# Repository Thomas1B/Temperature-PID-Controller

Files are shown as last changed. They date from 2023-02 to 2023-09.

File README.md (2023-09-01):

# Temperature PID Controller using an Arduino

This project uses a PID controller algorithm to heat up a heating cartridge and maintain an accurate temperature using an Arduino nano.
<br><br>

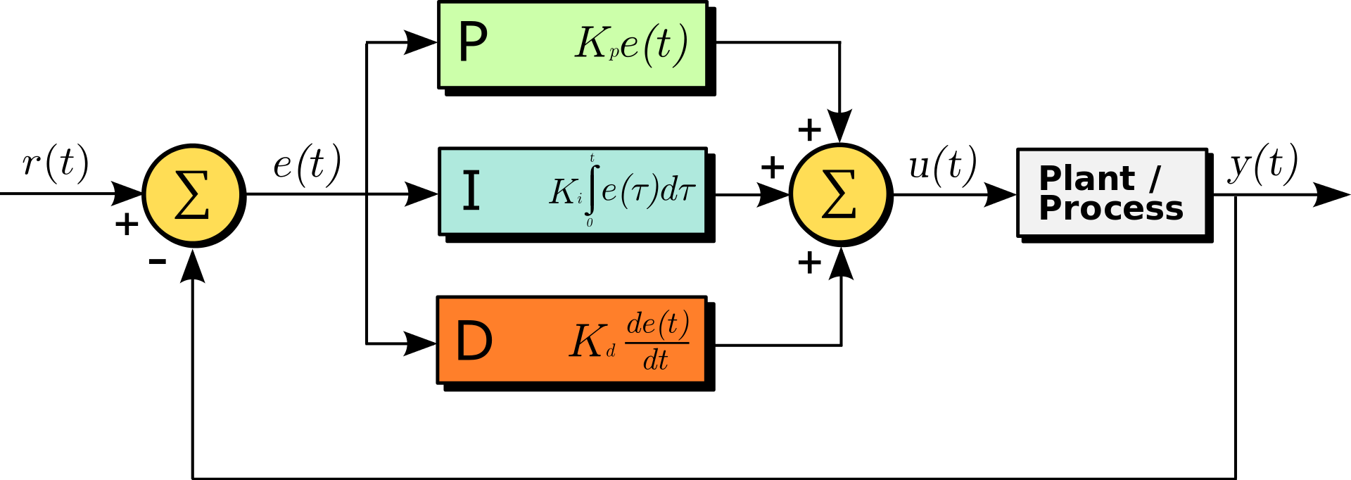
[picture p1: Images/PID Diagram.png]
PID Diagram
<br>

## Schematic

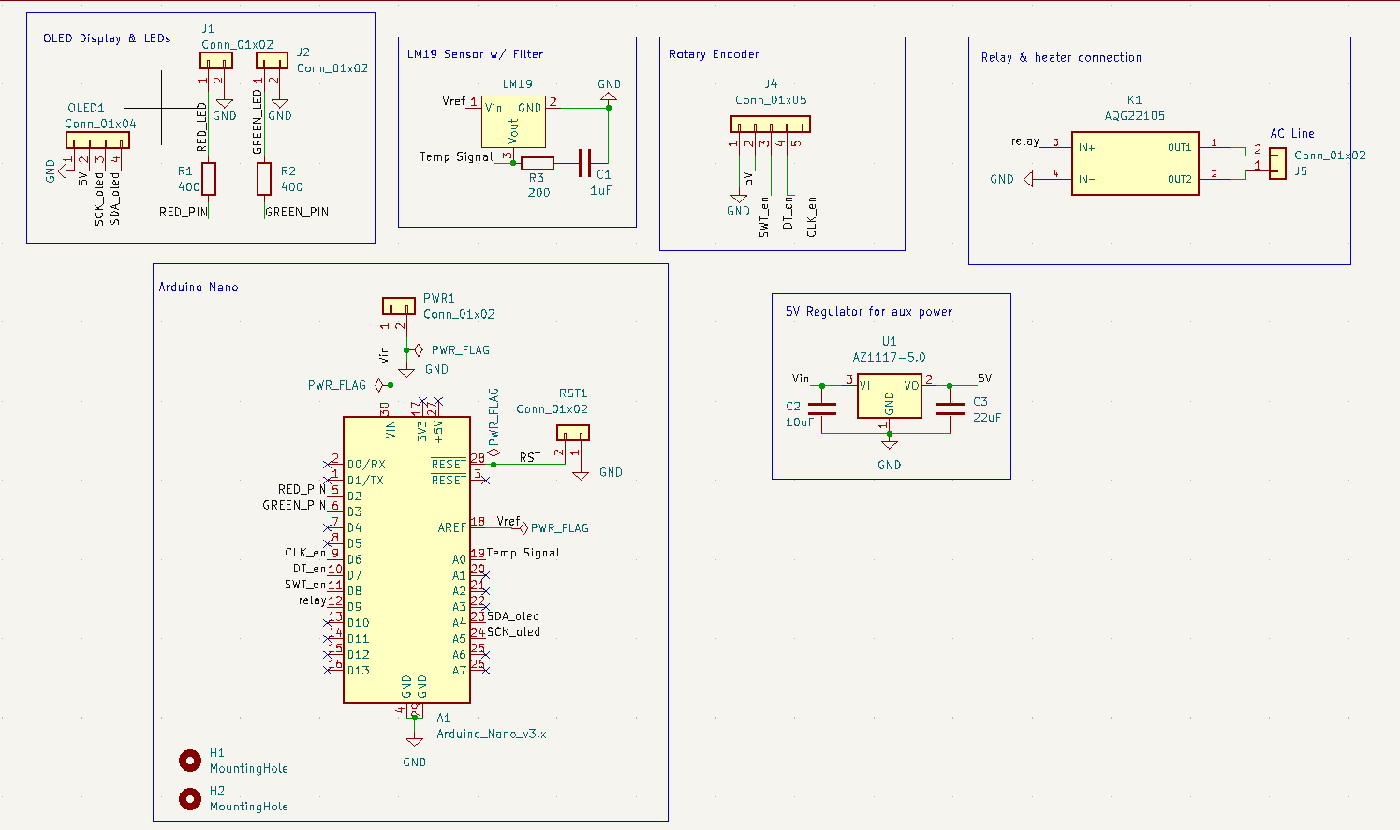
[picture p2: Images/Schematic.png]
Schematic
<br>

## Parts List

See `Parts_list.csv`

## Controls

1. Single-press to reset set temperature.
2. Double-press increase increment step for changing set temperature.
3. Press & hold to start up heating process.

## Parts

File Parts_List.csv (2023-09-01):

Index | Requested Quantity 1 | Pack Quantity 1 | Pack Type 1 | Digi-Key Part Number 1 | Unit Price 1 | Extended Price 1 | Minimum Order Quantity 1
1 | 1 | 1 | Bulk | 1050-ABX00028-ND | 19.71000 | $19.71 | 1
2 | 1 | 1 | Cut Tape (CT) | 296-48469-1-ND | 1.75000 | $1.75 | 1
3 | 1 | 1 | Tube | 255-2102-5-ND | 7.88000 | $7.88 | 1
4 | 4 | 4 | Bulk | 455-B2B-XH-A-ND | 0.22000 | $0.88 | 1
5 | 1 | 1 | Box | 455-B5B-XH-A-ND | 0.39000 | $0.39 | 1
6 | 1 | 1 | Bulk | 455-B4B-XH-A-ND | 0.32000 | $0.32 | 1
7 | 1 | 1 | Cut Tape (CT) | 1276-1066-1-ND | 0.14000 | $0.14 | 1
8 | 1 | 1 | Cut Tape (CT) | 1276-2891-1-ND | 0.26000 | $0.26 | 1
9 | 1 | 1 | Cut Tape (CT) | 1276-CL21A226MAYNNNECT-ND | 0.36000 | $0.36 | 1
10 | 1 | 1 | Cut Tape (CT) | AZ1117IH-5.0TRG1DICT-ND | 0.58000 | $0.58 | 1
11 | 1 | 1 | Bulk | 277-12547-ND | 0.73000 | $0.73 | 1
12 | 2 | 2 | Tray | S7013-ND | 1.42000 | $2.84 | 1
13 | 1 | 1 | Bulk | 754-1263-ND | 0.15000 | $0.15 | 1
14 | 1 | 1 | Bulk | 754-1264-ND | 0.15000 | $0.15 | 1
15 | 2 | 2 | Cut Tape (CT) | 311-392CRCT-ND | 0.15000 | $0.30 | 1
16 | 1 | 1 | Cut Tape (CT) | 13-RC0805FR-10200RLCT-ND | 0.15000 | $0.15 | 1
17 | 1 | 1 | Bulk | EG2025-ND | 2.36000 | $2.36 | 1
18 | 1 | 1 | Bulk | 455-2219-ND | 0.17000 | $0.17 | 1
19 | 1 | 1 | Bag | 455-2267-ND | 0.17000 | $0.17 | 1
20 | 1 | 1 | Bag | 455-2268-ND | 0.20000 | $0.20 | 1
21 | 4 | 4 | Bulk | 455-2266-ND | 0.15000 | $0.60 | 1
22 | 50 | 50 | Cut Tape (CT) | 455-4220-1-ND | 0.06680 | $3.34 | 1
23 | 1 | 1 | Bulk | 455-2248-ND | 0.30000 | $0.30 | 1

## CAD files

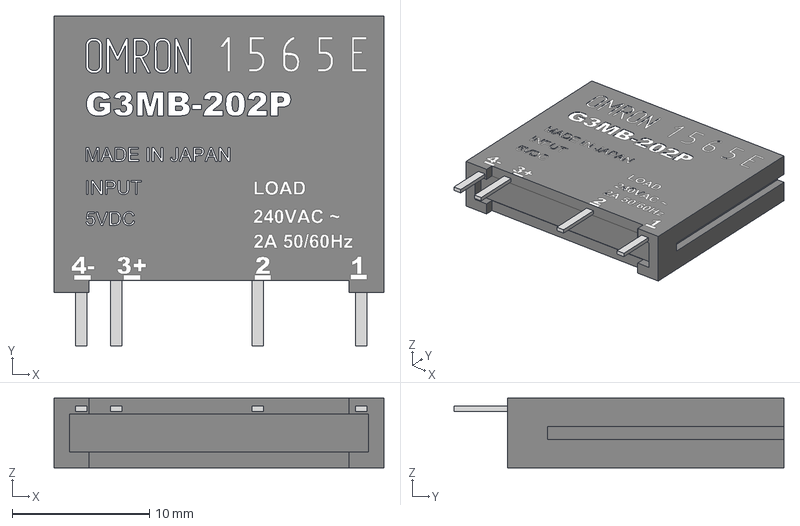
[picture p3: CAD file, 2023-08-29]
3D Models/G3MB-202P DC5 Relay.step
24.1 x 24.1 x 5.08 mm

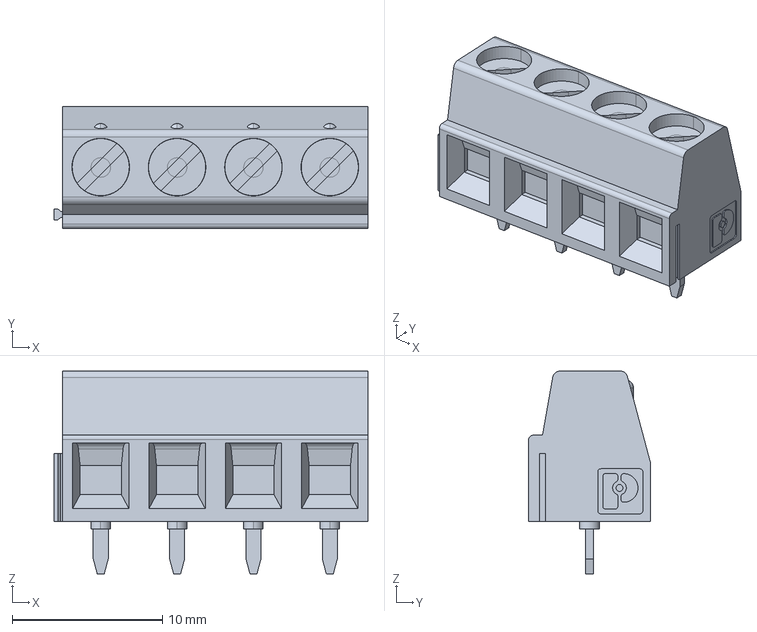
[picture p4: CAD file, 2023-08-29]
3D Models/terminal block - 4.stp
20.9 x 8.10 x 13.5 mm

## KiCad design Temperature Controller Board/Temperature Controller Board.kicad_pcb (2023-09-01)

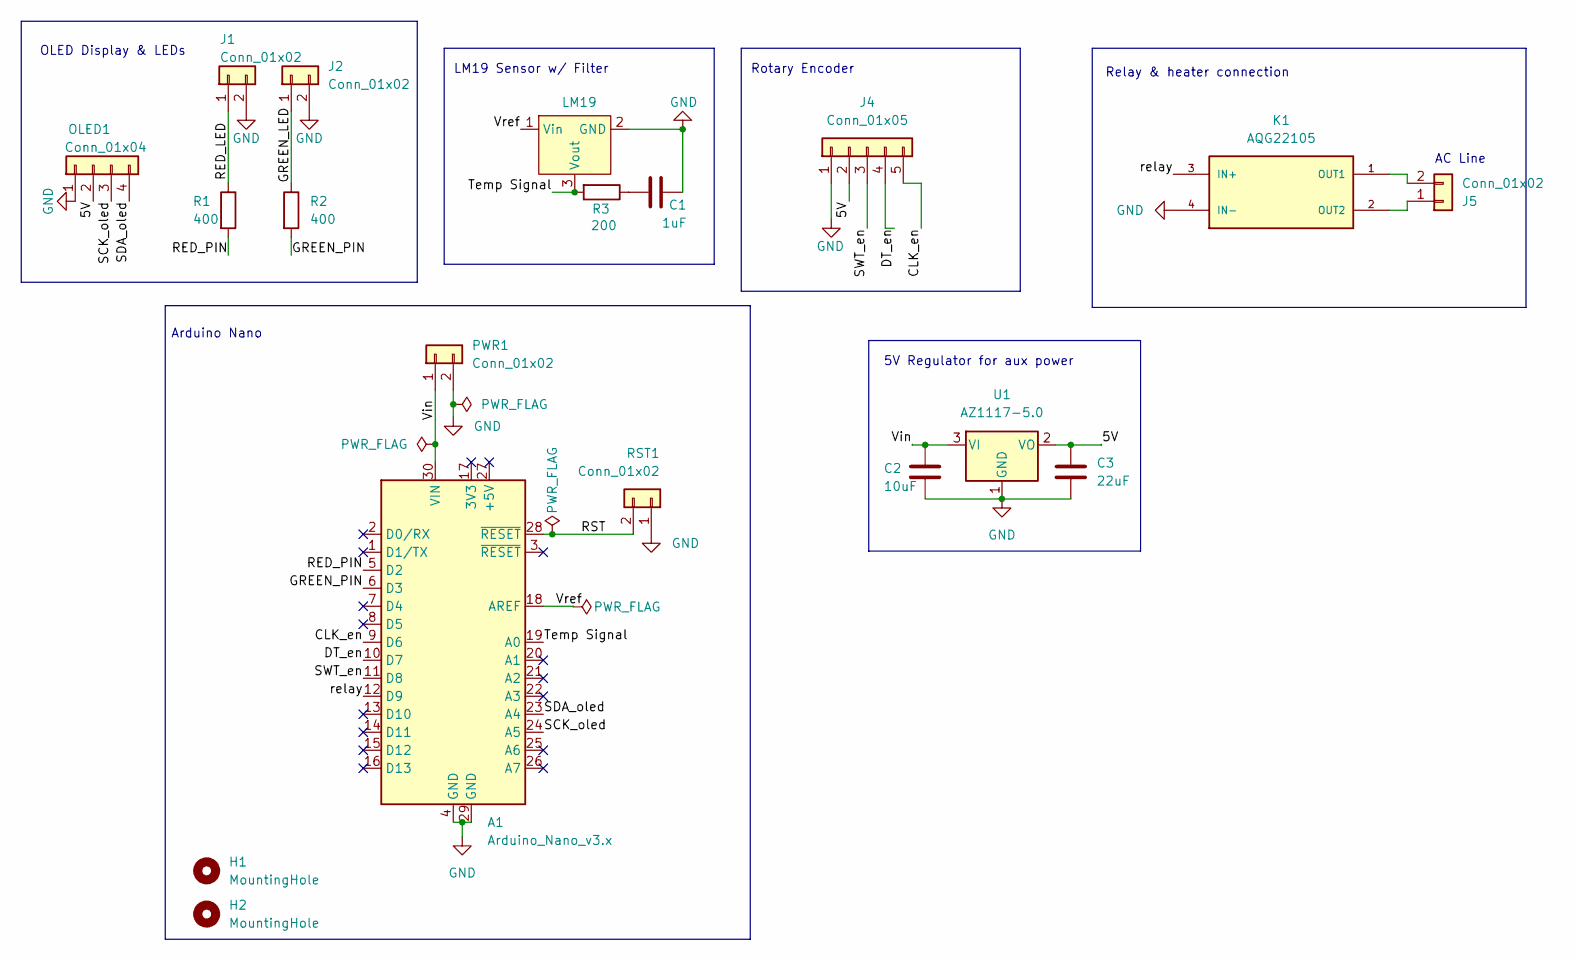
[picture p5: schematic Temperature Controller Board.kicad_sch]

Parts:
A1: Arduino_Nano_v3.x; Arduino Riser
C1: 1uF; C_0805_2012Metric_Pad1.18x1.45mm_HandSolder
C2: 10uF; C_0805_2012Metric_Pad1.18x1.45mm_HandSolder
C3: 22uF; C_0805_2012Metric_Pad1.18x1.45mm_HandSolder
H1, H2: MountingHole; MountingHole_3.2mm_M3
J1, J2: Conn_01x02; JST_XH_B2B-XH-A_1x02_P2.50mm_Vertical
J4: Conn_01x05; JST_XH_B5B-XH-A_1x05_P2.50mm_Vertical
J5: Conn_01x02; myTerminalBlock-2_P5.08mm
K1: AQG22105; RELAY_AQG22105
LM19: LM19; JST_XH_B3B-XH-AM_1x03_P2.50mm_Vertical
OLED1: Conn_01x04; JST_XH_B4B-XH-A_1x04_P2.50mm_Vertical
PWR1: Conn_01x02; JST_XH_B2B-XH-A_1x02_P2.50mm_Vertical
R1, R2: 400; R_0805_2012Metric_Pad1.20x1.40mm_HandSolder
R3: 200; R_0805_2012Metric_Pad1.20x1.40mm_HandSolder
RST1: Conn_01x02; JST_XH_B2B-XH-A_1x02_P2.50mm_Vertical
U1: AZ1117-5.0; SOT-223-3_TabPin2

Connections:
/5V: C3.1, J4.2, OLED1.2, U1.2 (VO)
/CLK_en: A1.9 (D6), J4.5
/DT_en: A1.10 (D7), J4.4
/GREEN_LED: J2.1, R2.1
/GREEN_PIN: A1.6 (D3), R2.2
/RED_LED: J1.1, R1.1
/RED_PIN: A1.5 (D2), R1.2
/RST: A1.28 (~RESET), RST1.2
/SCK_oled: A1.24 (A5), OLED1.3
/SDA_oled: A1.23 (A4), OLED1.4
/SWT_en: A1.11 (D8), J4.3
/Temp Signal: A1.19 (A0), LM19.3 (Vout), R3.2
/Vin: A1.30 (VIN), C2.1, PWR1.1, U1.3 (VI)
/Vref: A1.18 (AREF), LM19.1 (Vin)
/relay: A1.12 (D9), K1.3 (IN+)
GND: A1.4 (GND), A1.29 (GND), C1.1, C2.2, C3.2, J1.2, J2.2, J4.1, K1.4 (IN-), LM19.2 (GND), OLED1.1, PWR1.2, RST1.1, U1.1 (GND)
unnamed: C1.2, R3.1
unnamed: J5.1, K1.2 (OUT2)
unnamed: J5.2, K1.1 (OUT1)

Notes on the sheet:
Arduino Nano
5V Regulator for aux power
OLED Display & LEDs
AC Line
Rotary Encoder
Relay & heater connection
LM19 Sensor w/ Filter

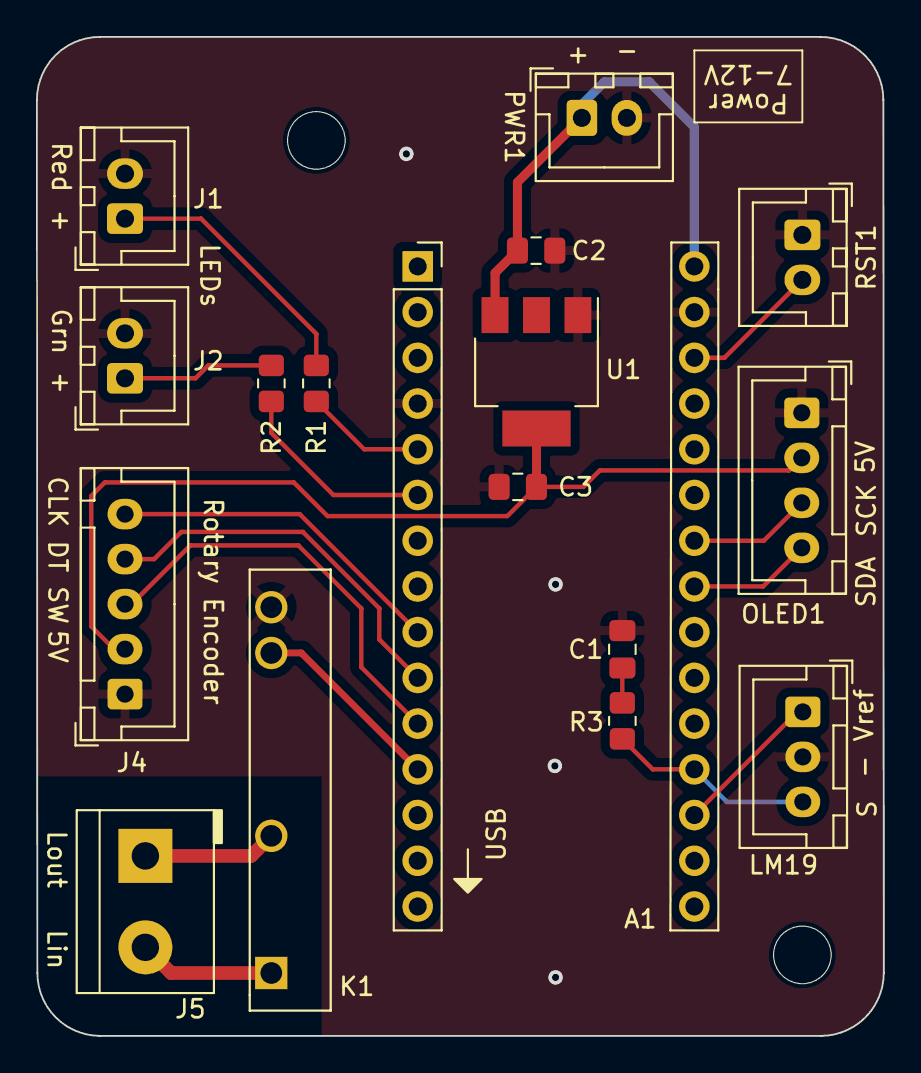
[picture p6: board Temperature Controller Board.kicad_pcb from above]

Board: 2 copper layers, 47.1 x 55.5 mm, 19 parts (0 on the bottom side), 19 nets.

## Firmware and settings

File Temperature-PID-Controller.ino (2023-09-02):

/*
Temperature PID Controller using a KY-40 rotary encoder.

Temperature is assumed to be in Celcius, unless otherwise stated.

Written by Thomas Bourgeois.

*/


#include <LiquidCrystal_I2C.h>
#include <BfButton.h>  // For Encoder.
#include <SPI.h>
#include <Wire.h>
#include <Adafruit_GFX.h>
#include <Adafruit_SSD1306.h>

#include <PID_v1.h>  // PID Controller library.


// ***************************************************** Defining Pins *****************************************************

// pins for Rotary Encoder
#define CLK 6
#define DT 7
#define SW 8
BfButton btn(BfButton::STANDALONE_DIGITAL, SW, true, LOW);  // defining Encoder button object

// pins for LEDs
#define RED_LED 2
#define GREEN_LED 3

#define relay_pin 9  // Relay pin

#define LM19_pin A7  // Reference voltage pin

// Declaring the OLED object.
// Data pin on arduino UNO/NANO: A4(SDA), A5(SCL)
#define SCREEN_WIDTH 128  // OLED display width, in pixels
#define SCREEN_HEIGHT 64  // OLED display height, in pixels
#define SCREEN_ADDRESS 0x3C
Adafruit_SSD1306 display(SCREEN_WIDTH, SCREEN_HEIGHT, &Wire);


// ***************************************************** Variables *****************************************************

const float Vref = 4.68;                        // Reference voltage lm19 is using.
const float temperature_range[] = { 25, 200 };  // allowable temperature range.

// Variables for Encoder:
float increment = 0.5;        // increment for each turn.
const float holdTime = 1000;  // how long to hold the button down.

// Variables for heater
bool powerState = false;

double const start_Setpoint = 30.0;  // starting temperature.
const long DelayofTempRead = 1000;   // period of sample.

// PID Coefficients
const float Kp = 1, Ki = 0.1, Kd = 0.01;

// ************************ DO NOT CHNAGE THESE VARIABLES ************************

double Setpoint = start_Setpoint;  // user set temperature.
double cur_temperature;            // current temperature
double Output;                     // output to heater.

// Creating PID Object
PID myPID(&cur_temperature, &Output, &Setpoint, Kp, Ki, Kd, DIRECT);  // Specify the links and initial tuning parameters

// Need for rotary Encoder
int preCLK;  // previous states
int preDT;
long TimeOfLastDebounce = 0;  // variables for debouncing.
const long DelayofDebounce = 0.01;

// delay time for reading temperaturez
long TimeOfLastRead = 0;


// ***************************************************** Main Program *****************************************************
void (*resetFunc)(void) = 0;

void setup() {
  // put your setup code here, to run once:
  Serial.begin(9600);


  /* Defining pinModes */
  pinMode(CLK, INPUT);  // Encoder
  pinMode(DT, INPUT);
  pinMode(SW, INPUT_PULLUP);
  pinMode(relay_pin, OUTPUT);

  pinMode(LM19_pin, INPUT);  // LM19 Temp Sensor

  pinMode(RED_LED, OUTPUT);  // LEDs
  pinMode(GREEN_LED, OUTPUT);

  btn.onPress(read_encoder_btn)               // single click
    .onDoublePress(read_encoder_btn)          // double click
    .onPressFor(read_encoder_btn, holdTime);  // hold for 1sec for turning on/off heating.

  // Read the initial state of Encoder.
  preCLK = digitalRead(CLK);
  preDT = digitalRead(DT);

  // initial read of temperature
  cur_temperature = get_temperature(LM19_pin);

  set_up_OLED();             // setting up OLED screen.
  myPID.SetMode(AUTOMATIC);  // turning on PID.
  run_relay(false);
  RED_LED_led(true);  // initial heater is turned off.
}



void loop() {

  // ************ Encoder stuff ************
  btn.read();
  if ((millis() - TimeOfLastDebounce) >= DelayofDebounce) {
    check_rotary();
    preCLK = digitalRead(CLK);
    preDT = digitalRead(DT);
    TimeOfLastDebounce = millis();
  }

  if ((millis() - TimeOfLastRead) >= DelayofTempRead) {
    TimeOfLastRead = millis();
    cur_temperature = get_temperature(LM19_pin);
    myPID.Compute();
    updateInfo();
    Serial.println(Output);

    if (powerState) {  // if user turned on power to relay.
      // future code
      if (Output > 0.0) {
        run_relay(true);
      }
    } else {
      run_relay(false);
    }
  }
}

// ***************************************************** Functions *****************************************************



void GREEN_LED_led(bool state) {
  // Function to turn on/off GREEN_LED led.
  digitalWrite(GREEN_LED, state);
}

void RED_LED_led(bool state) {
  // Function to turn on/off RED_LED led.
  digitalWrite(RED_LED, state);
}

void run_relay(bool state) {
  /*
  Function to run the relay.

    Parameters:
      state: true - on, false - off.
  */

  if (state) {
    digitalWrite(relay_pin, HIGH);
  } else {
    digitalWrite(relay_pin, LOW);
  }
}


void read_encoder_btn(BfButton* btn, BfButton::press_pattern_t pattern) {
  /*
    Function to handle the button on the Encoder.

      Parameters:
        btn: BfButton object.
        pattern: click pattern

  */

  switch (pattern) {

    case BfButton::SINGLE_PRESS:
      Setpoint = start_Setpoint;
      updateInfo();
      break;

    case BfButton::DOUBLE_PRESS:
      if (increment == 0.5) {
        increment = 10.0;
      } else {
        increment = 0.5;
      }
      break;

    case BfButton::LONG_PRESS:
      if (powerState) {  // turning heater off
        powerState = false;
        GREEN_LED_led(powerState);
        RED_LED_led(!powerState);
      } else {  // turning heater on.
        powerState = true;
        GREEN_LED_led(powerState);
        RED_LED_led(!powerState);
      }
      break;
  }
}

void check_rotary() {

  float dummy_temp = Setpoint;
  float var_Setpoint = Setpoint;  // temporary variable for allowable temperature range

  if ((preCLK == 0) && (preDT == 1)) {
    if ((digitalRead(CLK) == 1) && (digitalRead(DT) == 0)) {
      var_Setpoint += increment;
    }
    if ((digitalRead(CLK) == 1) && (digitalRead(DT) == 1)) {
      var_Setpoint -= increment;
    }
  }

  if ((preCLK == 1) && (preDT == 0)) {
    if ((digitalRead(CLK) == 0) && (digitalRead(DT) == 1)) {
      var_Setpoint += increment;
    }
    if ((digitalRead(CLK) == 0) && (digitalRead(DT) == 0)) {
      var_Setpoint -= increment;
    }
  }

  if ((preCLK == 1) && (preDT == 1)) {
    if ((digitalRead(CLK) == 0) && (digitalRead(DT) == 1)) {
      var_Setpoint += increment;
    }
    if ((digitalRead(CLK) == 0) && (digitalRead(DT) == 0)) {
      var_Setpoint -= increment;
    }
  }

  if ((preCLK == 0) && (preDT == 0)) {
    if ((digitalRead(CLK) == 1) && (digitalRead(DT) == 1)) {
      var_Setpoint += increment;
    }
    if ((digitalRead(CLK) == 1) && (digitalRead(DT) == 1)) {
      var_Setpoint -= increment;
    }
  }

  if (var_Setpoint != Setpoint) {
    if (var_Setpoint > temperature_range[1]) {
      var_Setpoint = temperature_range[1];
    } else if (var_Setpoint < temperature_range[0]) {
      var_Setpoint = temperature_range[0];
    }

    Setpoint = var_Setpoint;
    updateInfo();
  }
}

void OLED_msg(String text, boolean clear_display = true) {
  /*
    Function to display a message on the OLED Screen.
  */

  if (clear_display) {
    OLED_clear();
  };
  display.println(text);
  display.display();
}

void OLED_clear() {
  // Function to clear the OLED screen.
  display.clearDisplay();
  display.display();
  display.setCursor(0, 0);
}

void set_up_OLED() {
  /* 
    Function to set up the OLED and check if connection successful.
  */

  // SSD1306_SWITCHCAPVCC = generate display voltage from 3.3V internally
  if (!display.begin(SSD1306_SWITCHCAPVCC, SCREEN_ADDRESS)) {
    while (true) {
      continue;
    }
  } else {
    // Setting default text size and color
    display.setTextSize(2);
    display.setTextColor(WHITE);
    display.clearDisplay();

    // Displaying startup messege
    display.write("Starting");
    display.write("\nPID");
    display.write("\nController");
    display.display();
    delay(5000);
    OLED_clear();
  }
}


double get_temperature(int pin) {
  /*
  Function to convert the output voltage of a LM19 Sensor to temperature in Celsius.

  Parameter:
    Pin - int: analog pin to LM19 Sensor.

  Returns:
    temperature as a double.

  See https://www.ti.com/lit/ds/symlink/lm19.pdf, page 2 for the equation.
  */

  double Vo = analogRead(pin);
  Vo = Vo * Vref / 1023.0;  // mapping value to a voltage.

  // // Constants to simplify the equation
  double c1 = -1481.96;
  double c2 = 2.1962e6;
  double c3 = 1.8639;
  double c4 = 3.88e-6;

  return c1 + sqrt(c2 + ((c3 - Vo) / c4));
}

String double_to_string(double value, int decimal_places = 2) {
  /* 
  Function to convert a double to a String

    Parameters:
      value: double number to convert.
      round: what decimal place to round to
  */
  char buffer[10];
  dtostrf(value, 4, decimal_places, buffer);
  return String(buffer);
}


void updateInfo() {
  /*
  Function to update the display with temperature and setpoint.
  */
  display.clearDisplay();
  display.setCursor(0, 0);

  String text = "";

  // updating temperature
  if (cur_temperature > 0) {
    text = "T: " + double_to_string(cur_temperature, 1);
    display.print(text);
  } else {
    display.print("T: < 0");
  }
  display.write(247);
  display.print("C");

  // updating setpoint
  text = "\n\nSet T:\n" + double_to_string(Setpoint, 1);
  display.print(text);
  display.write(247);
  display.print("C");
  display.display();
}

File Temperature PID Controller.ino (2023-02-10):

/*
Temperature PID Controller  using an rotary encoder.

Written by Thomas Bourgeois.

*/
#include <LiquidCrystal_I2C.h>
#include <BfButton.h> // For Encoder.
#include <PID_v1.h> // PID Controller library.

LiquidCrystal_I2C lcd(0x27, 16, 2);

// ***************************************************** Variables *****************************************************
const float base_temperature = 35;
const float max_temperature = 100;

// Variables for Encoder
int currentStateCLK;
int lastState;
int curState;


// Variables for heater
bool powerState = false;

// PID Variables
double Setpoint = base_temperature;
double cur_temperature;
double Output;

//Specify the links and initial tuning parameters
PID myPID(&cur_temperature, &Output, &Setpoint, 2,5,1, DIRECT);


// ***************************************************** Defining Pins *****************************************************

// pins for encoder
#define CLK 2
#define DT 3
#define SW 4
BfButton btn(BfButton::STANDALONE_DIGITAL, SW, true, LOW);

// pins for RBG LED
#define RED A0
#define GREEN A1
#define BLUE A2


// ***************************************************** Functions *****************************************************

void led(int red, int green, int blue) {
  /*
    Function to color the rbg led

    Parameters:
      red, green, blue (int 0 - 255)
  */
  analogWrite(RED, red);
  analogWrite(GREEN, green);
  analogWrite(BLUE, blue);
}


void read_button(BfButton *btn, BfButton::press_pattern_t pattern) {
  // Function to read button on the Encoder.

  switch (pattern) {

    case BfButton::SINGLE_PRESS:
      Setpoint = base_temperature;
      // updateDisplay();
      break;

    case BfButton::LONG_PRESS:
      if (powerState) {
        powerState = false;
        led(0, 0, 0);
      } else {
        powerState = true;
        led(0, 255, 0);
      }
      break;
  }
}


void updateDisplay() {
  // Function to update display

  Serial.print("Set Temperature: ");
  Serial.println(Setpoint);
  Serial.print("C Temperature: ");
  Serial.println(Setpoint, 1);    

  lcd.setCursor(0, 0);
  lcd.print("Set Temp: ");
  lcd.print(Setpoint, 1);
  lcd.print((char)223);
  lcd.print("C");

  lcd.setCursor(0, 1);
  lcd.print("Cur Temp: ");
  lcd.print(Setpoint, 1);
  lcd.print((char)223);
  lcd.print("C");
}

// ***************************************************** Main Program *****************************************************

void setup() {
  // put your setup code here, to run once:
  lcd.init(); // initialize the lcd
  lcd.backlight();

  Serial.begin(9600);
  updateDisplay();

  pinMode(CLK, INPUT);
  pinMode(DT, INPUT);
  btn.onPress(read_button)  // single click
    // .onDoublePress(read_button) // double click
    .onPressFor(read_button, 1000);  // hold for 1sec for turning on/off heating.

  pinMode(RED, OUTPUT);
  pinMode(GREEN, OUTPUT);
  pinMode(BLUE, OUTPUT);

  // Read the initial state of Encoder.
  lastState = digitalRead(CLK);
}


void loop() {

  // ************ Encoder stuff ************
  btn.read();
  int curState = digitalRead(CLK);
  if (curState != lastState) {
    if (digitalRead(DT) != curState) {  // clockwise
      Setpoint += 0.5;
    } else {  // counter-clockwise
      Setpoint -= 0.5;
    }
    // if user goes beyond temperature allowable range.
    if (Setpoint > max_temperature) {
      Setpoint = max_temperature;
    } else if (Setpoint < base_temperature) {
      Setpoint = base_temperature;
    }
    updateDisplay();
  }
  lastState = curState;
  // ************************************************
  // Future code here...


  
}

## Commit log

2023-02-05 change LED function
2023-02-05 added PID library
2023-02-05 fixed encoder error
2023-02-05 SAFE SPOT, need to add LCD and PID control
2023-02-11 fixed temperature range
2023-02-11 change code for encoder, trying to fix debouncing
    [Temperature-PID-Controller.ino]
2023-02-21 added Kicad File
    [Circuit_nano.kicad_pcb, Circuit_nano.kicad_sch]
2023-03-23 testing ad590 sensor
2023-03-23 updating circuits
    [Circuit_nano.kicad_sch]
2023-06-22 testing new Temp Sensor, LM19
2023-06-22 removed testing old sensor
2023-07-07 added OLED and LM19 Sensor
2023-07-28 updated code and schematic
    [KiCad Circuit.kicad_pcb, KiCad Circuit.kicad_sch]
2023-07-28 removed old schematic
    [Circuit_nano.kicad_pcb, Circuit_nano.kicad_sch]
2023-08-29 added 3d models and images
    [G3MB-202P DC5 Relay.step, terminal block - 4.stp]
2023-08-29 updated Schematic and PCB
    [Temperature Controller Board.kicad_pcb, Temperature Controller Board.kicad_sch]
2023-08-29 removed old files
    [KiCad Circuit.kicad_pcb, KiCad Circuit.kicad_sch]
2023-09-01 added Parts List
    [Parts_List.csv]
2023-09-02 added PID code
